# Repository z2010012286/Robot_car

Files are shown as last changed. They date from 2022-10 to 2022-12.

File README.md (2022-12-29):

# T-Robot

（添加两张动图，自主导航+建图过程）

T-Robot是一个DIY的移动机器人(Moving Robot)，全面拥抱ROS2生态，可实现2D激光雷达地图重建和自主导航。

纯兴趣向，无任何技术创新，可作为ROS2入门参考使用；

底层采用micro_ros，彻底拥抱ROS2生态；

上层应用ROS2进行各个功能模块的快速开发；

本项目借鉴和学习了以下仓库：[linorobot2](https://github.com/linorobot/linorobot2) [fishbot](https://github.com/fishros/fishbot) [turtlebot3](https://github.com/ROBOTIS-GIT/turtlebot3)

# 仓库资料说明

- doc
- pictures
- firmware
- sunrise_x3pi
- host_machine
- models

# 机器人硬件部分

**均为淘宝采购，为避免广告嫌疑，不放链接~**

- **机器人底盘布局**



- **主控**：**esp32** (ESP-WROOM-32)+**旭日x3派**(2GB)

- **激光雷达**：LD14

- **IMU**：MPU9250

- **电机**： WGA12-N20直流减速电机 (12V, 1:50减速比)

- **电机驱动芯片**：4颗RZ7889

- **编码器**：AB双相增量式磁性霍尔编码器

- **电源**：12V锂电池；

  - 12V驱动电机；外置12V转5V模块提供DC-5V输出(最大电流4A)；

- **轮子**：4麦轮，直径48mm

- **结构件**：切割亚克力板、3D打印

# 机器人底层固件部分

# 0、固件说明

- 此固件基于Arduino框架，适用于esp32系列；不推荐使用ArduinoIDE进行编译(可能报错)；

- 推荐使用VScode+platformio，固件相关依赖可通过`platformio.ini`自动安装；

- 基于[micro_ros_arduino#v2.0.5foxy](https://github.com/micro-ROS/micro_ros_arduino#v2.0.5-foxy),可自行更改为其他版本，如`galactic`,`humble`等(可能需要极少的修改)；

- 由于`micro_ros_arduino`并不是原生支持`platformio`，因此在`platformio.ini`中需要手动指定相应硬件平台的`libmicroros.a`，使用如下命令(以esp32为例)：

  ```bash
  build_flags = 
    -L $PROJECT_DIR/lib/micro_ros_arduino/src/esp32/ -l libmicroros
  ```

  对官方micro_ros_arduino库进行了rebuild，因此不可以直接使用官方的库

- 若要使用官方micro_ros_arduino，需要更改odomertry message的Qos为default：

  - **改为default会导致发布频率降低**；

  ```c++
    //!!! 更改rclc_publisher_init_best_effort为rclc_publisher_init_default !!!
  RCCHECK(rclc_publisher_init_best_effort(
      &odom_publisher,
      &node,
      ROSIDL_GET_MSG_TYPE_SUPPORT(nav_msgs, msg, Odometry),
      "odom/unfiltered"));
  ```

- 使用wifi与上位机进行通讯；

- 若使用串口，确保串口波特率在480600bps以上，并修改src/main.cpp：

  ```c++
  set_microros_transports();
  //set_microros_wifi_transports("WIFI名称", "密码", "上位机IP", 8888);
  ```

# 1、各模块说明

## 1.1 lib/config

包含大部分宏定义，引脚定义等。

## 1.2 lib/encoder

c++封装的适用于esp32的编码器库，原作者仓库地址：[ESP32encoder](https://github.com/madhephaestus/ESP32Encoder.git)

- 本项目对其进行了必要修改，增加了`getRPM()`函数，以直接获取转速信息。

  ```c++
  float ESP32Encoder::getRPM(int counts_per_rev)  //counts_per_rev：每转一圈的编码器计数
  {
    counts_per_rev_ = counts_per_rev;
    int64_t encoder_ticks = getCount();
    // this function calculates the motor's RPM based on encoder ticks and delta time
    unsigned long current_time = micros();
    unsigned long dt = current_time - prev_update_time_;
    // convert the time from milliseconds to minutes
    double dtm = (double)dt / 60000000;
    double delta_ticks = encoder_ticks - prev_encoder_ticks_;
    // calculate wheel's speed (RPM)
    prev_update_time_ = current_time;
    prev_encoder_ticks_ = encoder_ticks;
    return ((delta_ticks / counts_per_rev_) / dtm);
  }
  ```

- 可配置实现不同的编码器计数方式：

```c++
//file: ESP32encoder.h
void attachSingleEdge(int aPintNumber, int bPinNumber); //1倍
void attachHalfQuad(int aPintNumber, int bPinNumber);  //2倍
void attachFullQuad(int aPintNumber, int bPinNumber);  //4倍
```

## 1.3 lib/imu

- `imu_interface.h`

  - 定义了IMU的`ros2 imu message`格式，可直接发送给ROS/ROS2使用；

  - `IMUInterface()`构造函数中初始化了`imu_msg.header`相关信息，不同版本写法略有不同；

  - 抽象了4个虚函数，方便适配不同类型的IMU；

    ```c++
    //file: imu_interface.h
    virtual geometry_msgs__msg__Vector3 readAccelerometer() = 0;
    virtual geometry_msgs__msg__Vector3 readGyroscope() = 0;
    virtual bool startSensor() = 0;
    virtual void calibrateGyro()=0;
    ```

- `default_imu.h`

  - 依赖[MPU9250库](https://github.com/hideakitai/MPU9250.git)，该库可通过platformio.ini文件进行自动安装，也可以手动下载添加；
  - 对`imu_interface.h`中的4个虚函数进行了实现；

## 1.4 lib/kinematics

c++封装的适用于求解小车底盘正逆运动学的库。适用于两轮差分、阿克曼、麦轮等。该库原地址：[kinematics](https://github.com/linorobot/linorobot2_hardware/tree/galactic/firmware/lib/kinematics)

小车轮距、轮径、转速等信息在`lib/config`中定义；

- 核心函数1：由线速度和角速度推算小车车轮转速

```c++
rpm getRPM(float linear_x, float linear_y, float angular_z);
```

- 核心函数2：由小车车轮转速推算线速度和角速度

```c++
velocities getVelocities(int rpm1, int rpm2, int rpm3, int rpm4);
```

## 1.5 lib/motor

`motor_interface.h`抽象了电机的各个功能，如正转、反转、停机等；

`motor.h`继承了`motor_interface`并对其各个功能进行了实现，并添加了`pwm_offset`;

`pwm_offset`是为了解决一些电机在低占空比pwm驱动下，电机不转动的问题；

## 1.6 lib/odemetry

定义了里程计`nav_msgs/msg/odometry`，用于发布`odometry message`；

- 核心函数1：获取当前的`odometry message`数据

  ```c++
  nav_msgs__msg__Odometry Odometry::getData()
  {
    return odom_msg_;
  }
  ```

- 核心函数2：传入速度信息，更新`odometry message`数据

```c++
void update(float vel_dt, float linear_vel_x, float linear_vel_y, float angular_vel_z);
```

## 1.7 lib/pid

顾名思义，电机的PID控制，不多解释了，看代码~

## 1.8 lib/micro_ros_arduino

基于官方的[micro_ros_arduino#v2.0.5foxy](https://github.com/micro-ROS/micro_ros_arduino#v2.0.5-foxy)，对其进行了必要修改，并进行了rebuild：

- 修改`UCLIENT_CUSTOM_TRANSPORT_MTU=1024`，使得采用best_effort的传输策略时，可以传输大于512Bytes的数据(主要是odometry message)；
- 修改`RMW_UXRCE_MAX_HISTORY=2`，减少RAM使用，避免内存溢出；
- 具体rebuild步骤可参考：https://github.com/micro-ROS/micro_ros_arduino/issues/1221#issuecomment-1329923473

## 1.9  src/main.cpp

- 初始化编码器、pid控制、电机等
- 创建2个publisher: odom和imu
- 创建1个subscriber: cmd_vel
- 创建3个软件定时器：2个用于publisher发布；1个用于控制机器人移动；

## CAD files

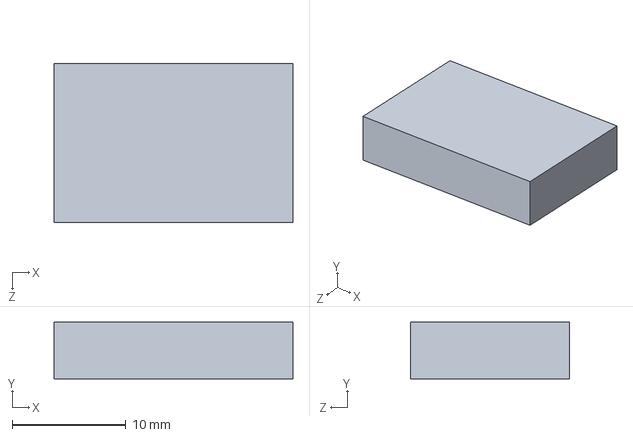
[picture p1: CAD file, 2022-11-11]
models_v2/imu.SLDPRT
21.0 x 5.00 x 14.0 mm

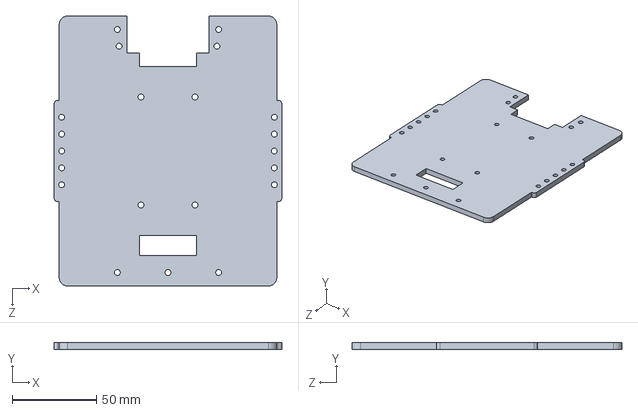
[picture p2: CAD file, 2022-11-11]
models_v2/plane_2.SLDPRT
135.0 x 4.00 x 160.0 mm

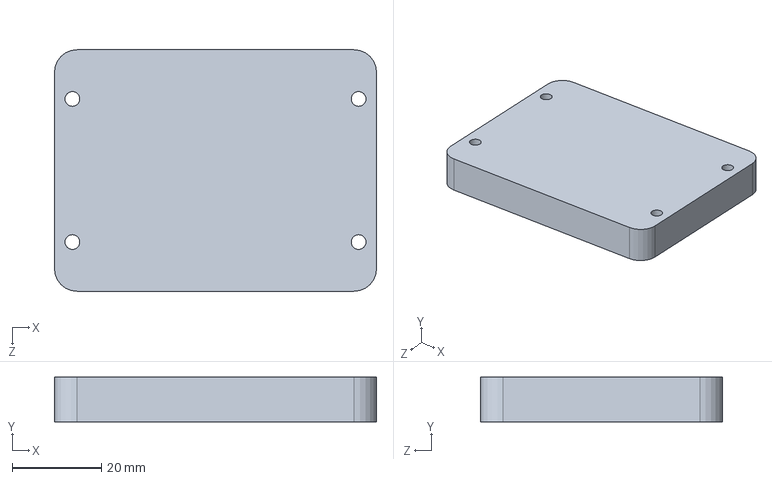
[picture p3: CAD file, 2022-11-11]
models_v2/pcb_board.SLDPRT
72.0 x 10.0 x 54.0 mm

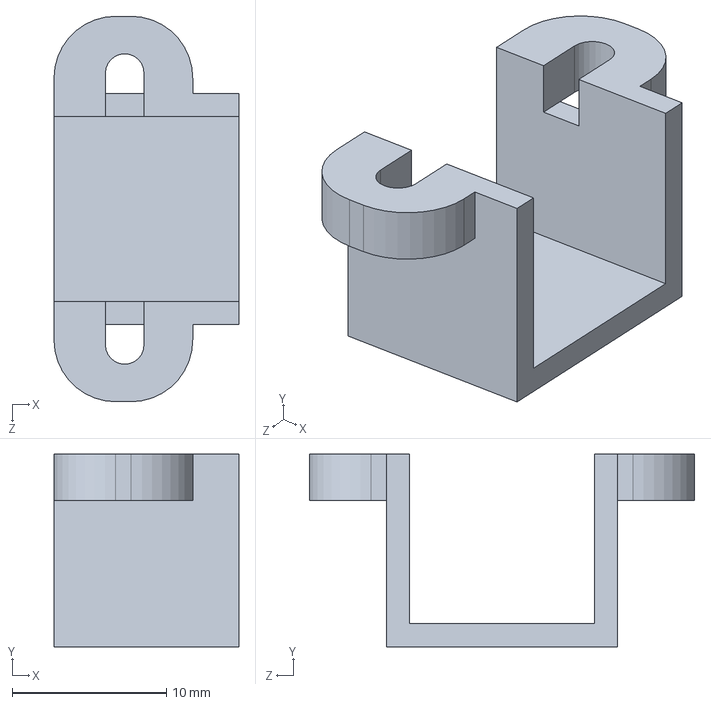
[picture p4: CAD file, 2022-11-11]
models_v2/电机固定扣.SLDPRT
12.0 x 12.5 x 25.0 mm

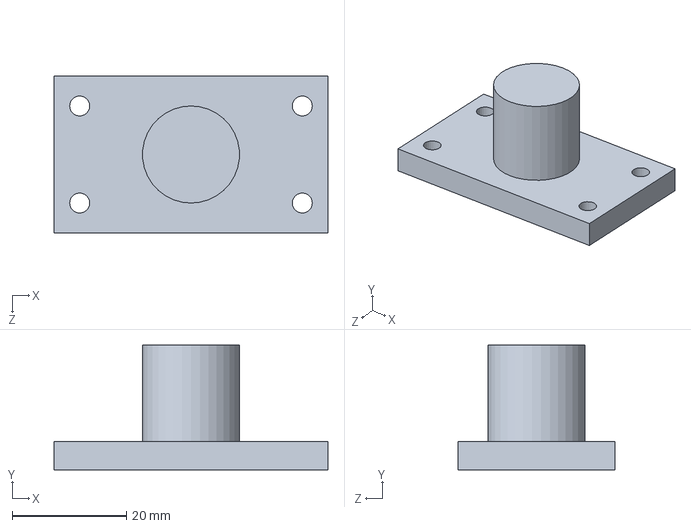
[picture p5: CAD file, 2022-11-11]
models_v2/camera.SLDPRT
48.0 x 21.9 x 27.5 mm

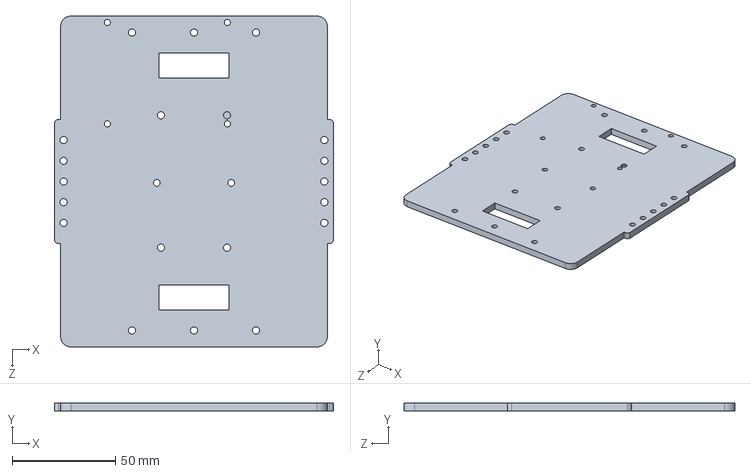
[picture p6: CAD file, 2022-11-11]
models_v2/plane_3v2.SLDPRT
135.0 x 4.00 x 160.0 mm

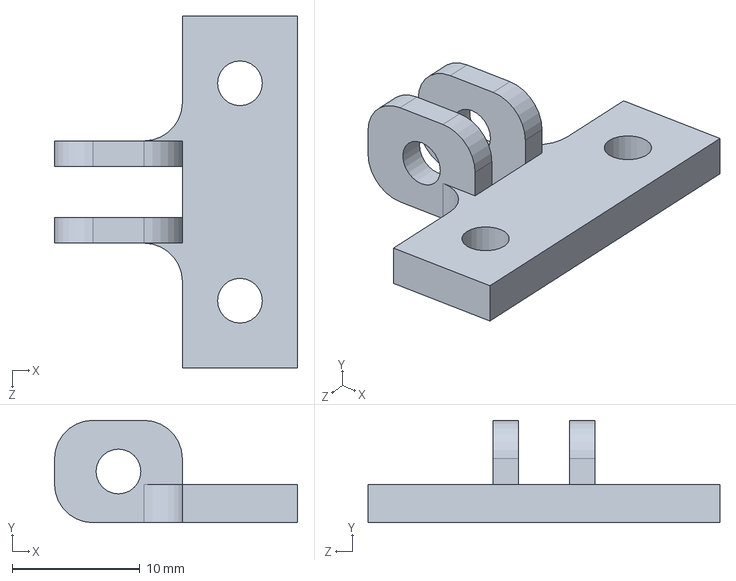
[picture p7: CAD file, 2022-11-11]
models_v2/camera组装.SLDPRT
19.0 x 8.00 x 27.5 mm

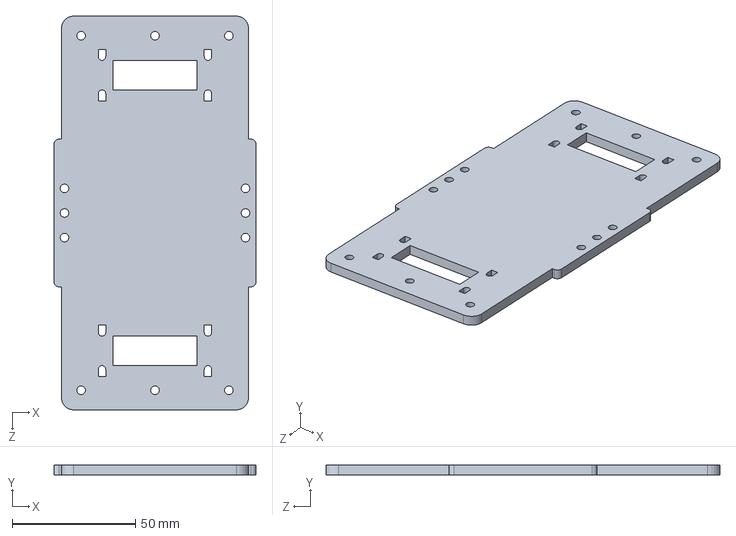
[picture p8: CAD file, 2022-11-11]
models_v2/plane.SLDPRT
82.0 x 4.00 x 160.0 mm

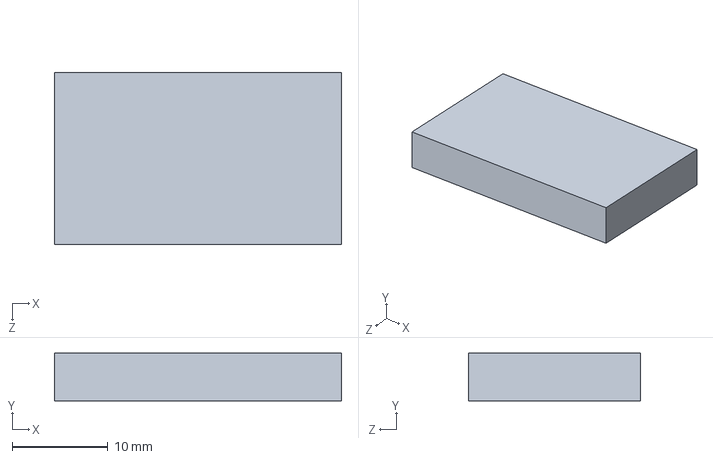
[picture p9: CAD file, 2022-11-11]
models_v2/DC-DC.SLDPRT
30.0 x 5.00 x 18.0 mm

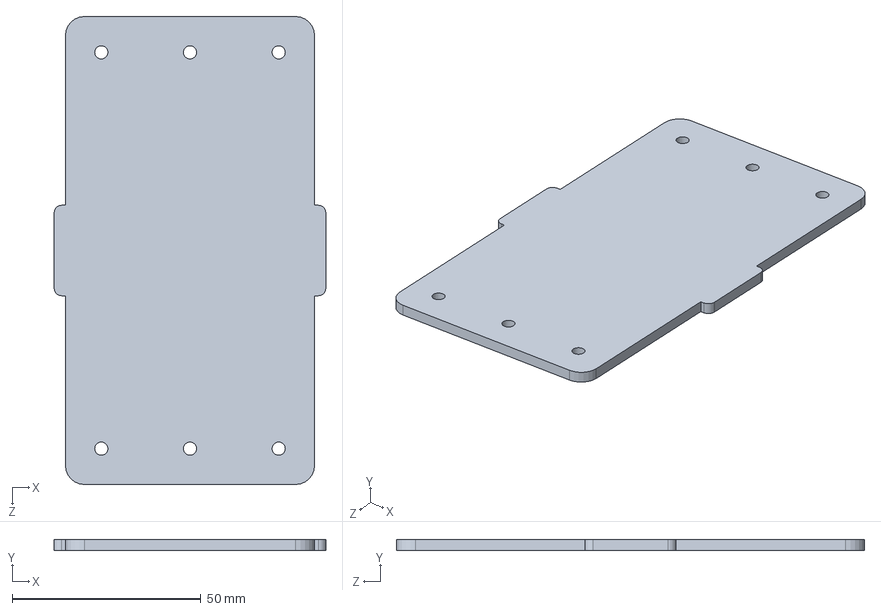
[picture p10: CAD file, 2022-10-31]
models_v2/plane_3.SLDPRT
72.0 x 3.00 x 124.0 mm

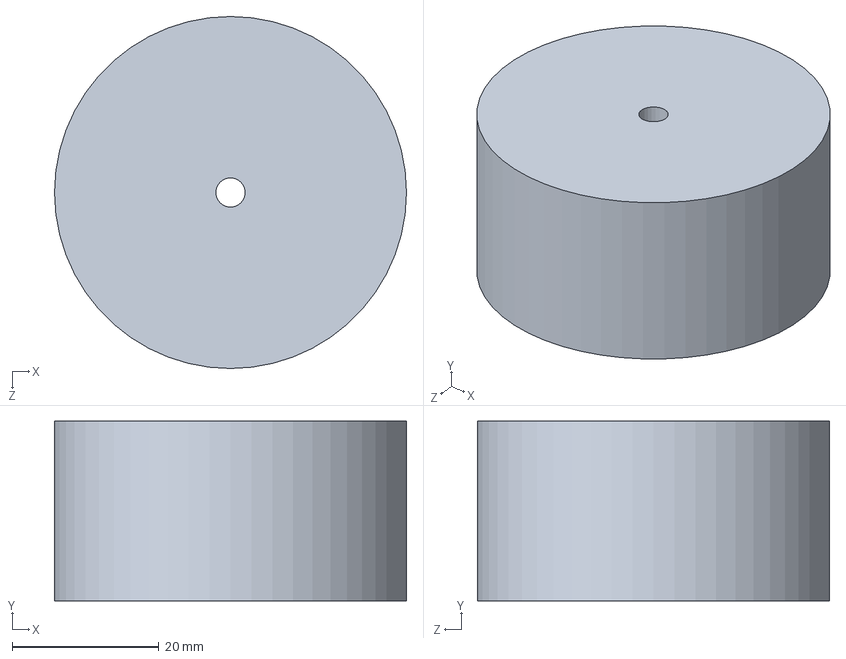
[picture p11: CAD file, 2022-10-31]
models_v2/wheel.SLDPRT
48.0 x 24.5 x 48.0 mm

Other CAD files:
models_v2/3mm_plane_2.DWG
models_v2/亚克力切割/4mm_plane.dwg
models_v2/亚克力切割/3mm_plane.dwg
models_v2/亚克力切割/3mm_plane2.dwg
models_v2/3mm_plane_3v2.DWG
models_v2/4mm_plane.DWG
models/3D打印/plane.STL
models/M3_10_6.SLDPRT
models/plane.SLDPRT
models_v2/M3_10_6.SLDPRT
models_v2/X3PI_3D_20220615175044.step
models_v2/battery.SLDPRT
models_v2/motor.SLDPRT

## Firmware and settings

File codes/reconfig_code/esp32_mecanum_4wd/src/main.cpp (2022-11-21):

#include <Arduino.h>
#include <micro_ros_arduino.h>
#include <stdio.h>

#include <rcl/rcl.h>
#include <rcl/error_handling.h>
#include <rclc/rclc.h>
#include <rclc/executor.h>

#include <nav_msgs/msg/odometry.h>
#include <sensor_msgs/msg/imu.h>
#include <geometry_msgs/msg/twist.h>
#include <geometry_msgs/msg/vector3.h>

#include "base_config.h"
#include "motor.h"
#include "kinematics.h"
#include "pid.h"
#include "odometry.h"
#include "default_imu.h"
#define ENCODER_USE_INTERRUPTS
// #define ENCODER_OPTIMIZE_INTERRUPTS
#include "encoder.h"
#define DEBUG 1

#define RCCHECK(fn)                  \
    {                                \
        rcl_ret_t temp_rc = fn;      \
        if ((temp_rc != RCL_RET_OK)) \
        {                            \
            rclErrorLoop();          \
        }                            \
    }
#define RCSOFTCHECK(fn)              \
    {                                \
        rcl_ret_t temp_rc = fn;      \
        if ((temp_rc != RCL_RET_OK)) \
        {                            \
        }                            \
    }
#define EXECUTE_EVERY_N_MS(MS, X)          \
    do                                     \
    {                                      \
        static volatile int64_t init = -1; \
        if (init == -1)                    \
        {                                  \
            init = uxr_millis();           \
        }                                  \
        if (uxr_millis() - init > MS)      \
        {                                  \
            X;                             \
            init = uxr_millis();           \
        }                                  \
    } while (0)

rcl_publisher_t odom_publisher;
rcl_publisher_t imu_publisher;
rcl_subscription_t twist_subscriber;

nav_msgs__msg__Odometry odom_msg;
sensor_msgs__msg__Imu imu_msg;
geometry_msgs__msg__Twist twist_msg;

rclc_executor_t executor;
rclc_support_t support;
rcl_allocator_t allocator;
rcl_node_t node;
rcl_timer_t control_timer;

unsigned long long time_offset = 0;
unsigned long prev_cmd_time = 0;
unsigned long prev_odom_update = 0;

enum states
{
    WAITING_AGENT,
    AGENT_AVAILABLE,
    AGENT_CONNECTED,
    AGENT_DISCONNECTED
} state;

Encoder motor1_encoder(MOTOR1_ENCODER_A, MOTOR1_ENCODER_B, COUNTS_PER_REV1, MOTOR1_ENCODER_INV);
Encoder motor2_encoder(MOTOR2_ENCODER_A, MOTOR2_ENCODER_B, COUNTS_PER_REV2, MOTOR2_ENCODER_INV);
Encoder motor3_encoder(MOTOR3_ENCODER_A, MOTOR3_ENCODER_B, COUNTS_PER_REV3, MOTOR3_ENCODER_INV);
Encoder motor4_encoder(MOTOR4_ENCODER_A, MOTOR4_ENCODER_B, COUNTS_PER_REV4, MOTOR4_ENCODER_INV);

Motor motor1_controller(MOTOR1_INV, MOTOR1_IN_A, MOTOR1_IN_B);
Motor motor2_controller(MOTOR2_INV, MOTOR2_IN_A, MOTOR2_IN_B);
Motor motor3_controller(MOTOR3_INV, MOTOR3_IN_A, MOTOR3_IN_B);
Motor motor4_controller(MOTOR4_INV, MOTOR4_IN_A, MOTOR4_IN_B);

PID motor1_pid(PWM_MIN, PWM_MAX, K_P, K_I, K_D);
PID motor2_pid(PWM_MIN, PWM_MAX, K_P, K_I, K_D);
PID motor3_pid(PWM_MIN, PWM_MAX, K_P, K_I, K_D);
PID motor4_pid(PWM_MIN, PWM_MAX, K_P, K_I, K_D);

Kinematics kinematics(
    Kinematics::MECANUM,
    MOTOR_MAX_RPM,
    MAX_RPM_RATIO,
    MOTOR_OPERATING_VOLTAGE,
    MOTOR_POWER_MAX_VOLTAGE,
    WHEEL_DIAMETER,
    LR_WHEELS_DISTANCE);

Odometry odometry;
MPU9250IMU imu;

void controlCallback(rcl_timer_t *timer, int64_t last_call_time);
void twistCallback(const void *msgin);
bool createEntities();
bool destroyEntities();
void fullStop();
void moveBase();
void publishData();
void syncTime();
struct timespec getTime();
void rclErrorLoop();
void flashLED(int n_times);

void setup()
{
    pinMode(LED_PIN, OUTPUT);
    digitalWrite(LED_PIN,HIGH);
    delay(500);
    Wire.begin();
    
    bool imu_ok = imu.init();
    if (!imu_ok)
    {
        while (1)
        {
            flashLED(3);
        }
    }
    
    set_microros_transports();
    state=WAITING_AGENT;
}

void loop()
{
    switch (state)
    {
    case WAITING_AGENT:
        EXECUTE_EVERY_N_MS(500, state = (RMW_RET_OK == rmw_uros_ping_agent(100, 1)) ? AGENT_AVAILABLE : WAITING_AGENT;);
        break;
    case AGENT_AVAILABLE:
        state = (true == createEntities()) ? AGENT_CONNECTED : WAITING_AGENT;
        if (state == WAITING_AGENT)
        {
            destroyEntities();
        }
        break;
    case AGENT_CONNECTED:
        EXECUTE_EVERY_N_MS(200, state = (RMW_RET_OK == rmw_uros_ping_agent(100, 1)) ? AGENT_CONNECTED : AGENT_DISCONNECTED;);
        if (state == AGENT_CONNECTED)
        {
            rclc_executor_spin_some(&executor, RCL_MS_TO_NS(100));
        }
        break;
    case AGENT_DISCONNECTED:
        destroyEntities();
        state = WAITING_AGENT;
        break;
    default:
        break;
    }
}

void controlCallback(rcl_timer_t *timer, int64_t last_call_time)
{
    RCLC_UNUSED(last_call_time);
    if (timer != NULL)
    {
        moveBase();
        publishData();
    }
}

void twistCallback(const void *msgin)
{
    digitalWrite(LED_PIN, !digitalRead(LED_PIN));

    prev_cmd_time = millis();
}

bool createEntities()
{
    allocator = rcl_get_default_allocator();
    // create init_options
    RCCHECK(rclc_support_init(&support, 0, NULL, &allocator));
    // create node
    RCCHECK(rclc_node_init_default(&node, "linorobot_base_node", "", &support));
    // create odometry publisher
    RCCHECK(rclc_publisher_init_default(
        &odom_publisher,
        &node,
        ROSIDL_GET_MSG_TYPE_SUPPORT(nav_msgs, msg, Odometry),
        "odom/unfiltered"));
    // create IMU publisher
    RCCHECK(rclc_publisher_init_default(
        &imu_publisher,
        &node,
        ROSIDL_GET_MSG_TYPE_SUPPORT(sensor_msgs, msg, Imu),
        "imu/data"));
    // create twist command subscriber
    // RCCHECK(rclc_subscription_init_default(
    //     &twist_subscriber,
    //     &node,
    //     ROSIDL_GET_MSG_TYPE_SUPPORT(geometry_msgs, msg, Twist),
    //     "cmd_vel"));
    // create timer for actuating the motors at 50 Hz (1000/20)
    const unsigned int control_timeout = 20;
    RCCHECK(rclc_timer_init_default(
        &control_timer,
        &support,
        RCL_MS_TO_NS(control_timeout),
        controlCallback));
    executor = rclc_executor_get_zero_initialized_executor();
    RCCHECK(rclc_executor_init(&executor, &support.context, 3, &allocator));
    // RCCHECK(rclc_executor_add_subscription(
    //     &executor,
    //     &twist_subscriber,
    //     &twist_msg,
    //     &twistCallback,
    //     ON_NEW_DATA));
    RCCHECK(rclc_executor_add_timer(&executor, &control_timer));

    // synchronize time with the agent
    syncTime();
    digitalWrite(LED_PIN, HIGH);

    return true;
}

bool destroyEntities()
{
    rmw_context_t *rmw_context = rcl_context_get_rmw_context(&support.context);
    (void)rmw_uros_set_context_entity_destroy_session_timeout(rmw_context, 0);

    rcl_publisher_fini(&odom_publisher, &node);
    rcl_publisher_fini(&imu_publisher, &node);
    rcl_subscription_fini(&twist_subscriber, &node);
    rcl_node_fini(&node);
    rcl_timer_fini(&control_timer);
    rclc_executor_fini(&executor);
    rclc_support_fini(&support);

    digitalWrite(LED_PIN, HIGH);

    return true;
}

void fullStop()
{
    twist_msg.linear.x = 0.0;
    twist_msg.linear.y = 0.0;
    twist_msg.angular.z = 0.0;

    motor1_controller.brake();
    motor2_controller.brake();
    motor3_controller.brake();
    motor4_controller.brake();
}

void moveBase()
{
    // brake if there's no command received, or when it's only the first command sent
    if (((millis() - prev_cmd_time) >= 200))
    {
        twist_msg.linear.x = 0.0;
        twist_msg.linear.y = 0.0;
        twist_msg.angular.z = 0.0;

        digitalWrite(LED_PIN, HIGH);
    }
    // get the required rpm for each motor based on required velocities, and base used
    Kinematics::rpm req_rpm = kinematics.getRPM(
        twist_msg.linear.x,
        twist_msg.linear.y,
        twist_msg.angular.z);

    // get the current speed of each motor
    float current_rpm1 = motor1_encoder.getRPM();
    float current_rpm2 = motor2_encoder.getRPM();
    float current_rpm3 = motor3_encoder.getRPM();
    float current_rpm4 = motor4_encoder.getRPM();

    // the required rpm is capped at -/+ MAX_RPM to prevent the PID from having too much error
    // the PWM value sent to the motor driver is the calculated PID based on required RPM vs measured RPM
    motor1_controller.spin(motor1_pid.compute(req_rpm.motor1, current_rpm1));
    motor2_controller.spin(motor2_pid.compute(req_rpm.motor2, current_rpm2));
    motor3_controller.spin(motor3_pid.compute(req_rpm.motor3, current_rpm3));
    motor4_controller.spin(motor4_pid.compute(req_rpm.motor4, current_rpm4));

    Kinematics::velocities current_vel = kinematics.getVelocities(
        current_rpm1,
        current_rpm2,
        current_rpm3,
        current_rpm4);

    unsigned long now = millis();
    float vel_dt = (now - prev_odom_update) / 1000.0;
    prev_odom_update = now;
    odometry.update(
        vel_dt,
        current_vel.linear_x,
        current_vel.linear_y,
        current_vel.angular_z);
}

void publishData()
{
    odom_msg = odometry.getData();
    imu_msg = imu.getData();

    struct timespec time_stamp = getTime();

    odom_msg.header.stamp.sec = time_stamp.tv_sec;
    odom_msg.header.stamp.nanosec = time_stamp.tv_nsec;

    imu_msg.header.stamp.sec = time_stamp.tv_sec;
    imu_msg.header.stamp.nanosec = time_stamp.tv_nsec;

    RCSOFTCHECK(rcl_publish(&imu_publisher, &imu_msg, NULL));
    RCSOFTCHECK(rcl_publish(&odom_publisher, &odom_msg, NULL));
}

void syncTime()
{
    // get the current time from the agent
    unsigned long now = millis();
    RCCHECK(rmw_uros_sync_session(10));
    unsigned long long ros_time_ms = rmw_uros_epoch_millis();
    // now we can find the difference between ROS time and uC time
    time_offset = ros_time_ms - now;
}

struct timespec getTime()
{
    struct timespec tp = {0};
    // add time difference between uC time and ROS time to
    // synchronize time with ROS
    unsigned long long now = millis() + time_offset;
    tp.tv_sec = now / 1000;
    tp.tv_nsec = (now % 1000) * 1000000;

    return tp;
}

void rclErrorLoop()
{
    while (true)
    {
        flashLED(2);
    }
}

void flashLED(int n_times)
{
    for (int i = 0; i < n_times; i++)
    {
        digitalWrite(LED_PIN, HIGH);
        delay(150);
        digitalWrite(LED_PIN, LOW);
        delay(150);
    }
    delay(1000);
}

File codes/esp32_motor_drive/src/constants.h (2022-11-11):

/*
 * @Author: Tianci Zhang
 * @Email: tianci_zhang@tju.edu.cn
 * @Date: 2022-10-26 19:49:27
 * @LastEditors: Tianci Zhang
 * @LastEditTime: 2022-11-11 22:02:30
 * @FilePath: \esp32_motor_drive\src\constants.h
 * @Description:
 *
 * Copyright (c) 2022 by tianci_zhang@tju.edu.cn, All Rights Reserved.
 */

#ifndef CONSTANTS_H
#define CONSTANTS_H
#include <PIDController.h>
#define MOTOR1 1
#define MOTOR2 2
#define MOTOR3 3
#define MOTOR4 4

#define ENCODER1_A 21
#define ENCODER1_B 22
#define ENCODER2_A 34
#define ENCODER2_B 35
#define ENCODER3_A 4
#define ENCODER3_B 5
#define ENCODER4_A 26
#define ENCODER4_B 25

#define MOTOR1_PWMOUT1 16
#define MOTOR1_PWMOUT2 17
#define MOTOR2_PWMOUT1 14
#define MOTOR2_PWMOUT2 15
#define MOTOR3_PWMOUT1 18
#define MOTOR3_PWMOUT2 19
#define MOTOR4_PWMOUT1 12
#define MOTOR4_PWMOUT2 13

#define PWM_OFFSET 50
#define PID_MIN_OUTPUT -255
#define PID_MAX_OUTPUT 255

#endif

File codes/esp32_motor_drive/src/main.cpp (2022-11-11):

#include <Arduino.h>
#include <PIDController.h>
#include "constants.h"
#include "motor_init.h"
#include "motor_control.h"
extern volatile long int encoder1_count;
extern volatile long int encoder2_count;
extern volatile long int encoder3_count;
extern volatile long int encoder4_count; // stores the current encoder count

double Kp = 7.8;  // Proportional constant
double Ki = 0.05; // Integral Constant
double Kd = 61;   // Derivative Constant
hw_timer_t *timer = NULL;

unsigned long int motor1_target = 0;
unsigned long int motor2_target = 0;
unsigned long int motor3_target = 0;
unsigned long int motor4_target = 0;

char incomingByte; // parses and stores each individual character one by one

PIDController pidcontroller1;
PIDController pidcontroller2;
PIDController pidcontroller3;
PIDController pidcontroller4;

void ARDUINO_ISR_ATTR onTimer();
void serial_tune_pid();

void setup()
{
  Serial.begin(115200); // Serial for Debugging
  timer = timerBegin(0, 80, true);
  timerAttachInterrupt(timer, &onTimer, true);
  timerAlarmWrite(timer, 50000, true); // 1000000为1秒
  timerAlarmEnable(timer);
  four_motors_init();
  pid_controller_init(pidcontroller1, pidcontroller2, pidcontroller3, pidcontroller4);
}

void loop()
{
  serial_tune_pid();
  delay(500);
}

void ARDUINO_ISR_ATTR onTimer()
{
  static int i;
  position_update(pidcontroller1, MOTOR1, encoder1_count, motor1_target);
  position_update(pidcontroller2, MOTOR2, encoder2_count, motor2_target);
  position_update(pidcontroller3, MOTOR3, encoder3_count, motor3_target);
  position_update(pidcontroller4, MOTOR4, encoder4_count, motor4_target);
  if (i % 1 == 0)
  {
    // Serial.print("收到的设定值：");
    // Serial.println(integerValue); // print the incoming value for debugging
    // Serial.print("编码器值：");
    Serial.println(encoder4_count); // print the final encoder count.
  }
  i++;
}

void serial_tune_pid()
{
  while (Serial.available() > 0)
  {
    //    integerValue = Serial.parseInt(); // stores the integerValue
    incomingByte = Serial.read(); // stores the /n character
    switch (incomingByte)
    {
    case '\n':
      continue;
      break;
    case 'q':
      Kp += 0.1;
      break;
    case 'a':
      Kp -= 0.1;
      break;
    case 'w':
      Ki += 0.1;
      break;
    case 's':
      Ki -= 0.1;
      break;
    case 'e':
      Kd += 0.1;
      break;
    case 'd':
      Kd -= 0.1;
      break;
    case 'r':
      motor1_target += 358;
      motor2_target += 358;
      motor3_target += 358;
      motor4_target += 358; // 358一圈
      break;
    case 'f':
      motor1_target -= 358;
      motor2_target -= 358;
      motor3_target -= 358;
      motor4_target -= 358;
      break;
    case 'p':
      Serial.println("--------------------");
      Serial.print("kp:");
      Serial.print(Kp);
      Serial.print("  ki:");
      Serial.print(Ki);
      Serial.print("  kd:");
      Serial.println(Kd);
      Serial.println("--------------------");
      break;
    }
  }
  if (Kp < 0)
    Kp = 0;
  if (Ki < 0)
    Ki = 0;
  if (Kd < 0)
    Kd = 0;
  if (motor1_target < 0)
    motor1_target = 0;
  if (motor2_target < 0)
    motor2_target = 0;
  if (motor3_target < 0)
    motor3_target = 0;
  if (motor4_target < 0)
    motor4_target = 0;

  pidcontroller1.tune(Kp, Ki, Kd);
}

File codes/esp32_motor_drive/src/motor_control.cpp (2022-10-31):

/*
 * @Author: Tianci Zhang
 * @Email: tianci_zhang@tju.edu.cn
 * @Date: 2022-10-26 20:44:29
 * @LastEditors: Tianci Zhang
 * @LastEditTime: 2022-10-30 11:20:15
 * @FilePath: \esp32_motor_drive\src\motor_control.cpp
 * @Description:
 *
 * Copyright (c) 2022 by tianci_zhang@tju.edu.cn, All Rights Reserved.
 */
#include "constants.h"
void pid_controller_init(PIDController &pid1, PIDController &pid2, PIDController &pid3, PIDController &pid4)
{
    pid1.begin(); // initialize the PID instance
    //  pidcontroller.tune(260, 2.7, 2000); // Tune the PID, arguments: kP, kI, kD
    pid1.tune(7.8, 0.05, 61); // Tune the PID, arguments: kP, kI, kD
    pid1.limit(PID_MIN_OUTPUT, PID_MAX_OUTPUT);

    pid2.begin(); // initialize the PID instance
    //  pidcontroller.tune(260, 2.7, 2000); // Tune the PID, arguments: kP, kI, kD
    pid2.tune(7.8, 0.05, 61); // Tune the PID, arguments: kP, kI, kD
    pid2.limit(PID_MIN_OUTPUT, PID_MAX_OUTPUT);

    pid3.begin(); // initialize the PID instance
    //  pidcontroller.tune(260, 2.7, 2000); // Tune the PID, arguments: kP, kI, kD
    pid3.tune(7.8, 0.05, 61); // Tune the PID, arguments: kP, kI, kD
    pid3.limit(PID_MIN_OUTPUT, PID_MAX_OUTPUT);

    pid4.begin(); // initialize the PID instance
    //  pidcontroller.tune(260, 2.7, 2000); // Tune the PID, arguments: kP, kI, kD
    pid4.tune(7.8, 0.05, 61); // Tune the PID, arguments: kP, kI, kD
    pid4.limit(PID_MIN_OUTPUT, PID_MAX_OUTPUT);
};

void motor_cw(int motor, int power)
{
    if (power >= PWM_OFFSET)
    {
        switch (motor)
        {
        case 1:
            analogWrite(MOTOR1_PWMOUT1, power); // rotate the motor if the value is grater than 100
            analogWrite(MOTOR1_PWMOUT2, 0);
            break;
        case 2:
            analogWrite(MOTOR2_PWMOUT1, power); // rotate the motor if the value is grater than 100
            analogWrite(MOTOR2_PWMOUT2, LOW);
            break;
        case 3:
            analogWrite(MOTOR3_PWMOUT1, power); // rotate the motor if the value is grater than 100
            analogWrite(MOTOR3_PWMOUT2, LOW);
            break;
        case 4:
            analogWrite(MOTOR4_PWMOUT1, power); // rotate the motor if the value is grater than 100
            analogWrite(MOTOR4_PWMOUT2, LOW);
            break;
        default:
            break;
        }
    }
    else
    {
        switch (motor)
        {
        case 1:
            analogWrite(MOTOR1_PWMOUT1, LOW);
            analogWrite(MOTOR1_PWMOUT2, LOW);
            break;
        case 2:
            analogWrite(MOTOR2_PWMOUT1, LOW);
            analogWrite(MOTOR2_PWMOUT2, LOW);
            break;
        case 3:
            analogWrite(MOTOR3_PWMOUT1, LOW);
            analogWrite(MOTOR3_PWMOUT2, LOW);
            break;
        case 4:
            analogWrite(MOTOR4_PWMOUT1, LOW);
            analogWrite(MOTOR4_PWMOUT2, LOW);
            break;
        default:
            break;
        }
    }
}

void motor_ccw(int motor, int power)
{
    if (power >= PWM_OFFSET)
    {
        switch (motor)
        {
        case 1:
            analogWrite(MOTOR1_PWMOUT2, power); // rotate the motor if the value is grater than 100
            analogWrite(MOTOR1_PWMOUT1, LOW);
            break;
        case 2:
            analogWrite(MOTOR2_PWMOUT2, power); // rotate the motor if the value is grater than 100
            analogWrite(MOTOR2_PWMOUT1, LOW);
            break;
        case 3:
            analogWrite(MOTOR3_PWMOUT2, power); // rotate the motor if the value is grater than 100
            analogWrite(MOTOR3_PWMOUT1, LOW);
            break;
        case 4:
            analogWrite(MOTOR4_PWMOUT2, power); // rotate the motor if the value is grater than 100
            analogWrite(MOTOR4_PWMOUT1, LOW);
            break;
        default:
            break;
        }
    }
    else
    {
        switch (motor)
        {
        case 1:
            analogWrite(MOTOR1_PWMOUT2, LOW);
            analogWrite(MOTOR1_PWMOUT1, LOW);
            break;
        case 2:
            analogWrite(MOTOR2_PWMOUT2, LOW);
            analogWrite(MOTOR2_PWMOUT1, LOW);
            break;
        case 3:
            analogWrite(MOTOR3_PWMOUT2, LOW);
            analogWrite(MOTOR3_PWMOUT1, LOW);
            break;
        case 4:
            analogWrite(MOTOR4_PWMOUT2, LOW);
            analogWrite(MOTOR4_PWMOUT1, LOW);
            break;
        default:
            break;
        }
    }
}

void position_update(PIDController &pid, int motor, volatile long int encoder_count, int target_value)
{
    static int j;
    int motor_pwm_value = 0;
    pid.setpoint(target_value);
    motor_pwm_value = pid.compute(encoder_count);
    if (motor_pwm_value >= 0)
    { // if the motor_pwm_value is greater than zero we rotate the  motor in clockwise direction
        motor_pwm_value = constrain(motor_pwm_value + PWM_OFFSET, 0, PID_MAX_OUTPUT);
        motor_ccw(motor, motor_pwm_value);
        if (j % 30000 == 0)
        {
            Serial.print("PWM实际值:");
            Serial.println(motor_pwm_value);
        }
    }
    else
    { // else we move it in a counter clockwise direction
        motor_pwm_value = constrain(motor_pwm_value - PWM_OFFSET, PID_MIN_OUTPUT, 0);
        motor_cw(motor, abs(motor_pwm_value));
        if (j % 300000 == 0)
        {
            Serial.print("PWM实际值:");
            Serial.println(motor_pwm_value);
        }
    }
    j++;
}

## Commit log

2022-10-31 固件代码
2022-11-11 20221111调试
    [3mm_plane.dwg, 3mm_plane2.dwg, 3mm_plane_2.DWG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]
2022-11-21 20221121更新
